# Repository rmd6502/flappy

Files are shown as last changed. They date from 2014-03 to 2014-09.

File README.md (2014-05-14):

flappy
======

This is the source folder for the Flappy Bird in a Box project.

Contents
--------

**circuit** Eagle files

**flappy_final_v8** Not really the final version, but the final version before github

**Arduino** Modifications for the stock Arduino 1.0.5 to enable compiling for the Flappy board.

Installation Instructions
-------------------------

* Install the [Arduino](http://arduino.cc) 1.0.5 IDE.
* Copy the libraries and hardware directories into the sketchbook directory for your platform
  * C:\Documents and Settings\My Documents\Arduino
  * ${HOME}/sketchbook
  * ${HOME}/Documents/Arduino
* Install the latest avr-gcc toolchain
  * AVR Studio from [Atmel](http://www.atmel.com) if you're on Windows,
  * sudo apt-get install avr-gcc
  * [Crosspack AVR for Mac](http://www.obdev.at/products/crosspack/index.html)
* Go to the Arduino install directory
  * C:\Program Files(x86)\Arduino
  * Not sure for linux - /usr/local/Arduino?
  * /Applications/Arduino.app
* Find the hardware/tools subdirectory
* mv the avr directory to e.g. avr.save - this is an old version of the toolchain that seems to 
have problems
* Copy or link the root of your newest toolchain as 'avr' in the hardware/tools directory.
* Restart the Arduino IDE
* You should be able to choose Flappy Board as your board type, and Dragon ISP as the programmer
* Choose "upload using programmer" instead of Upload

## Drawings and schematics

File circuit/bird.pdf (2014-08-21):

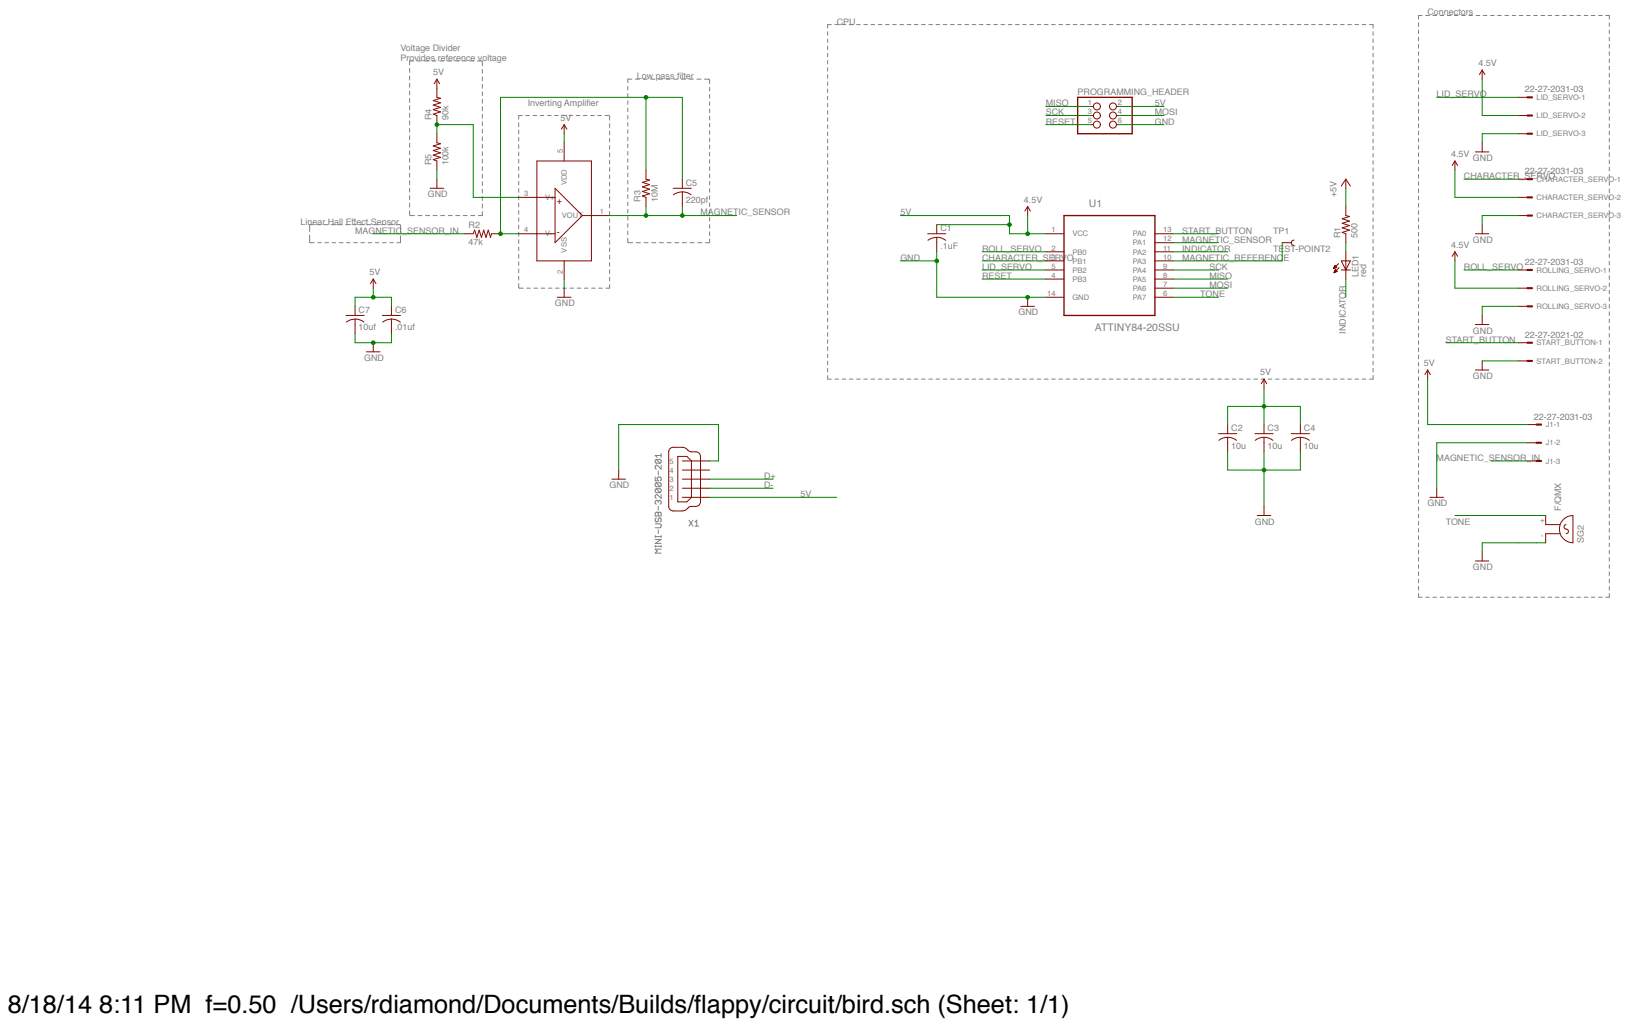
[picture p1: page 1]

Linear Hall Effect Sensor

8/18/14 8:11 PM f=0.50 /Users/rdiamond/Documents/Builds/flappy/circuit/bird.sch (Sheet: 1/1)

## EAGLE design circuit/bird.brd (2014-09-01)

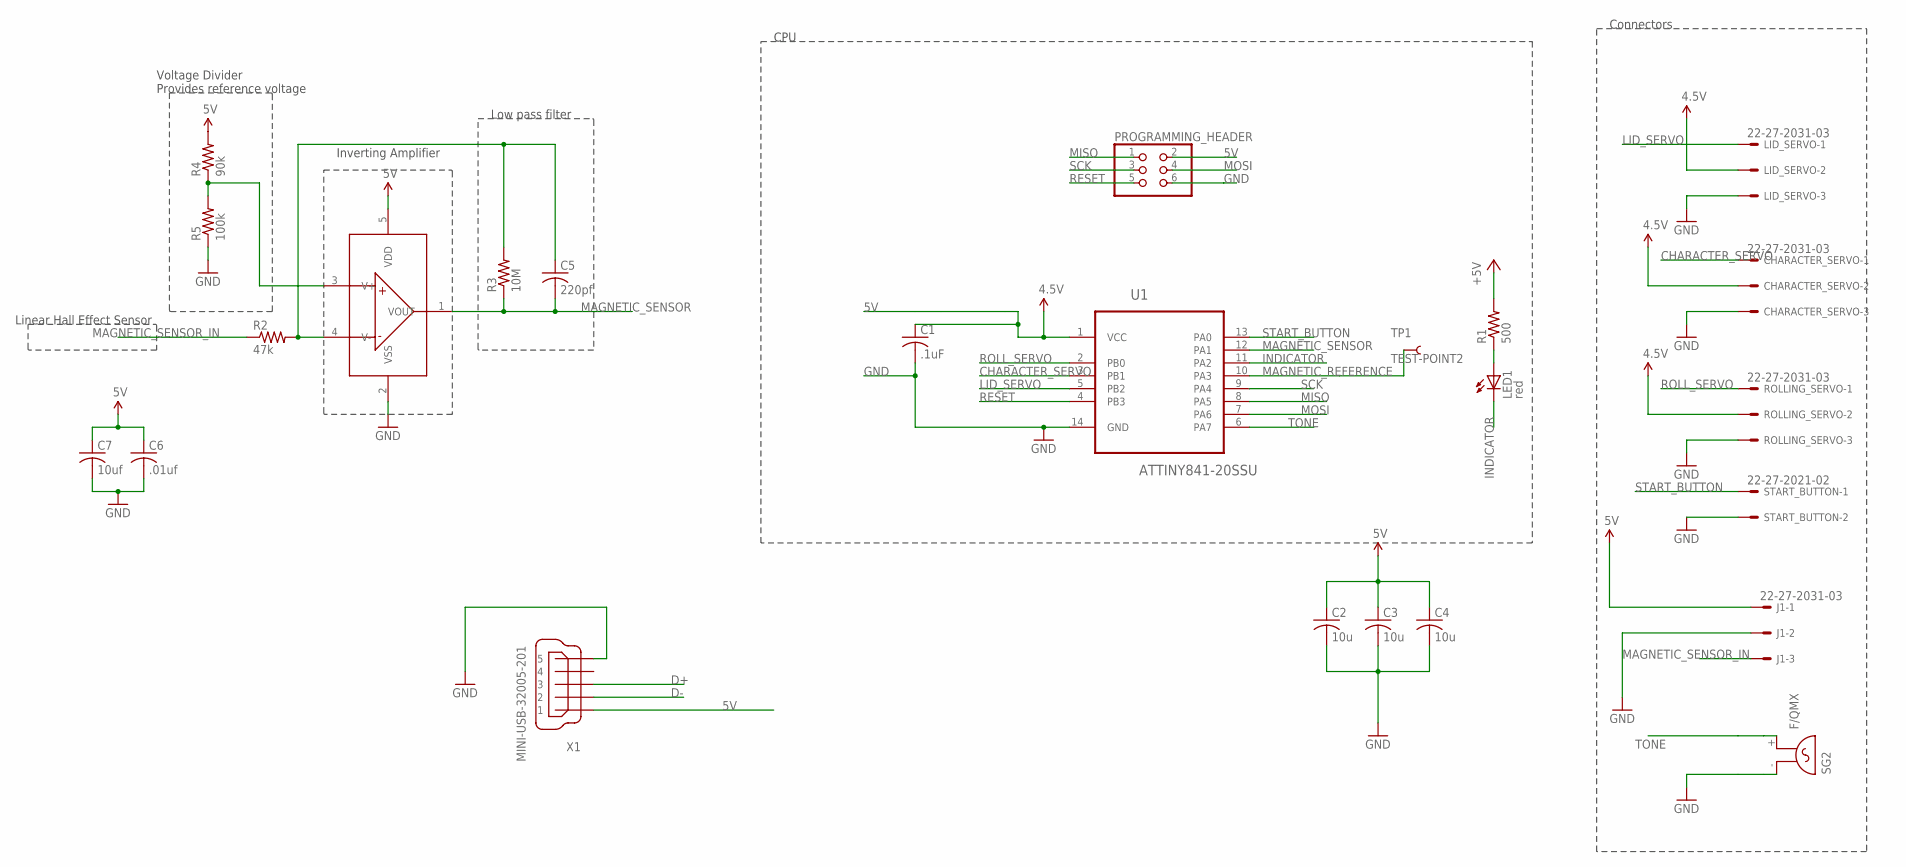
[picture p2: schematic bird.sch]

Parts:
C1: .1uF; C0603
C2, C3, C4: 10u; C0805
C5: 220pf; C0603
C6: .01uf; C0603
C7: 10uf; C0805
CHARACTER_SERVO: 22-27-2031-03; 6410-03
J1: 22-27-2031-03; 6410-03
LED1: red; SML1206
LID_SERVO: 22-27-2031-03; 6410-03
PROGRAMMING_HEADER: PINHD-2X3; 2X03
R1: 500; R0603
R2: 47k; R0603
R3: 10M; R0603
R4: 90k; R0603
R5: 100k; R0603
ROLLING_SERVO: 22-27-2031-03; 6410-03
SG2: F/QMX
START_BUTTON: 22-27-2021-02; 6410-02
TP1: TEST-POINT2; PAD.02X.02
U1: ATTINY841-20SSU; SOIC127P600X175-14N
U$5: MCP601; SOT23-5
X1: MINI-USB-32005-201; 32005-201

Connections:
5V: C1.1, C2.1, C3.1, C4.1, C6.1, C7.1, CHARACTER_SERVO.2, J1.1, LID_SERVO.2, PROGRAMMING_HEADER.2, R1.2, R4.2, ROLLING_SERVO.2, U1.1 (VCC), U$5.5 (VDD), X1.1
CHARACTER_SERVO: CHARACTER_SERVO.1, U1.3 (PB1)
D+: X1.3
D-: X1.2
GND: C1.2, C2.2, C3.2, C4.2, C6.2, C7.2, CHARACTER_SERVO.3, J1.2, LID_SERVO.3, PROGRAMMING_HEADER.6, R5.1, ROLLING_SERVO.3, SG2.- (1), START_BUTTON.2, U1.14 (GND), U$5.2 (VSS), X1.5
INDICATOR: LED1.C, U1.11 (PA2)
LID_SERVO: LID_SERVO.1, U1.5 (PB2)
MAGNETIC_REFERENCE: TP1.P$1, U1.10 (PA3)
MAGNETIC_SENSOR: C5.2, R3.1, U1.12 (PA1), U$5.1 (VOUT)
MAGNETIC_SENSOR_IN: J1.3, R2.1
MISO: PROGRAMMING_HEADER.1, U1.8 (PA5)
MOSI: PROGRAMMING_HEADER.4, U1.7 (PA6)
unnamed: LED1.A, R1.1
unnamed: C5.1, R2.2, R3.2, U$5.4 (V-)
unnamed: R4.1, R5.2, U$5.3 (V+)
RESET: PROGRAMMING_HEADER.5, U1.4 (PB3)
ROLL_SERVO: ROLLING_SERVO.1, U1.2 (PB0)
SCK: PROGRAMMING_HEADER.3, U1.9 (PA4)
START_BUTTON: START_BUTTON.1, U1.13 (PA0)
TONE: SG2.+ (2), U1.6 (PA7)

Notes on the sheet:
Linear Hall Effect Sensor
Voltage Divider Provides reference voltage
Low pass filter
Inverting Amplifier
CPU
Connectors

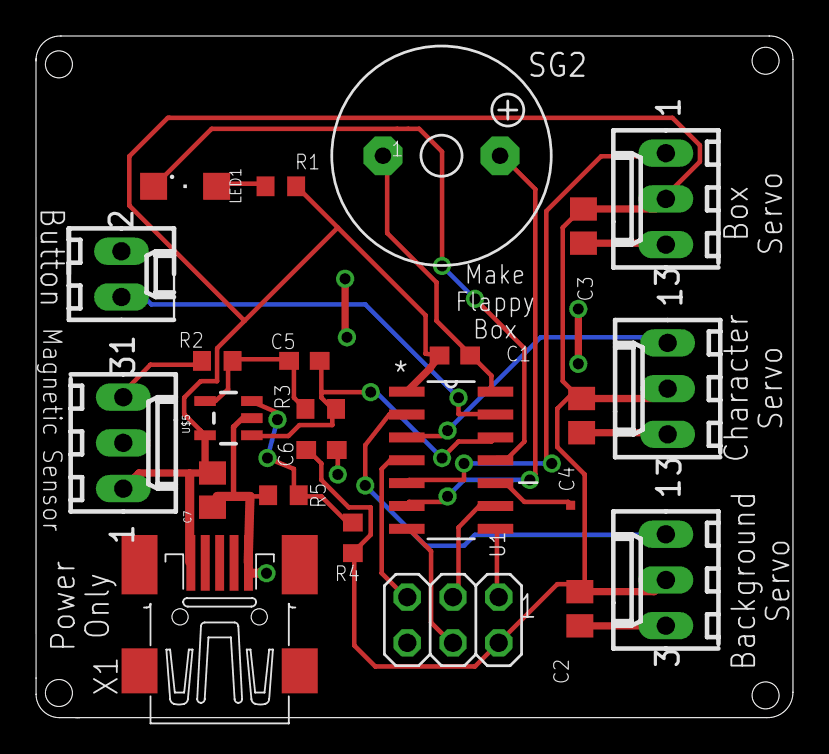
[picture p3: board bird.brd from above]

Board: 2 copper layers, 42.1 x 37.9 mm, 24 parts (0 on the bottom side), 18 nets.

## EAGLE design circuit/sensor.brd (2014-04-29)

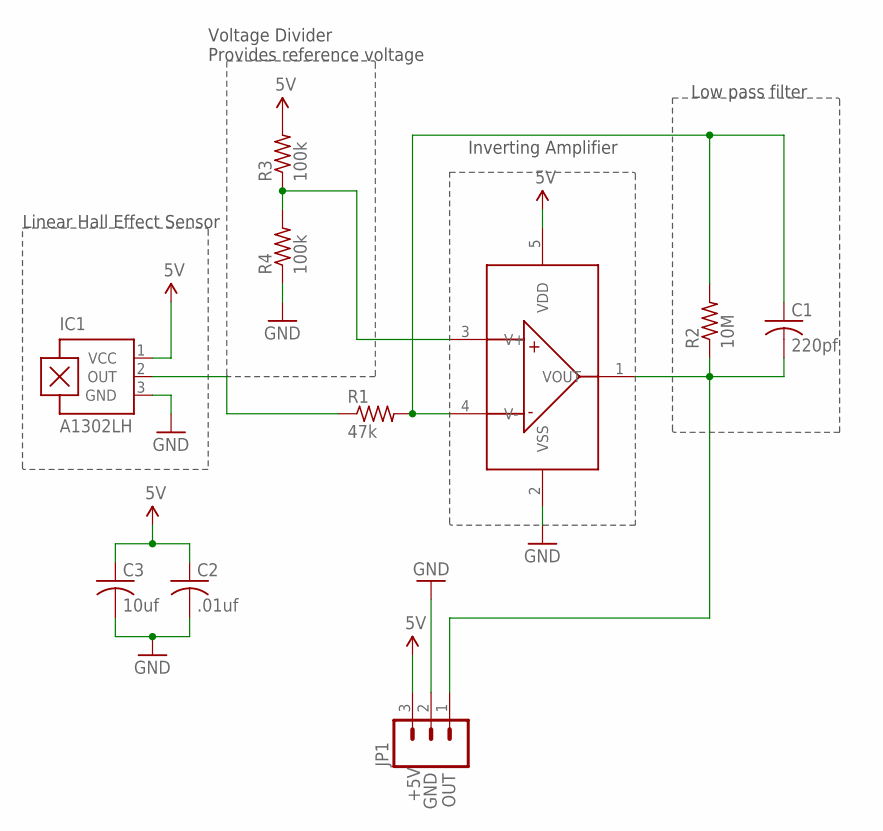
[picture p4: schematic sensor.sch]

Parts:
C1: 220pf; C0805
C2: .01uf; C0805
C3: 10uf; C0805
IC1: A1302LH; SOT23-W
JP1: M03PTH; 1X03
R1: 47k; R0805
R2: 10M; R0805
R3, R4: 100k; R0805
U$1: MCP601; SOT23-5

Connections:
5V: C2.1, C3.1, IC1.1 (VCC), JP1.3, R3.2, U$1.5 (VDD)
GND: C2.2, C3.2, IC1.3 (GND), JP1.2, R4.1, U$1.2 (VSS)
unnamed: C1.2, JP1.1, R2.1, U$1.1 (VOUT)
unnamed: IC1.2 (OUT), R1.1
unnamed: C1.1, R1.2, R2.2, U$1.4 (V-)
unnamed: R3.1, R4.2, U$1.3 (V+)

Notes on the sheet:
+5V
GND
OUT
Linear Hall Effect Sensor
Voltage Divider Provides reference voltage
Low pass filter
Inverting Amplifier

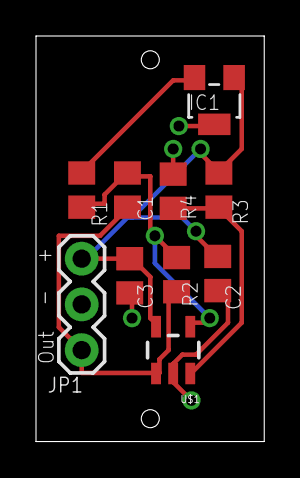
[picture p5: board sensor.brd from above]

Board: 2 copper layers, 12.7 x 22.5 mm, 10 parts (0 on the bottom side), 6 nets.

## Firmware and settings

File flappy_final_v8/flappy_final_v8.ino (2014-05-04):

#include <Servo.h> 
#include "pitches.h"

#define BOX_OPEN 90
#define BOX_CLOSE 0

#define CHARACTER_BOTTOM 40
#define CHARACTER_TOP 85

const uint8_t magnetPin = 1;     // the number of the reed switch
const uint8_t buttonPin = 0;  // the number of the pushbutton pin for bird
const uint8_t speakerPin = 7;
const uint8_t rollServoPin = 10;
const uint8_t characterServoPin = 9;
const uint8_t lidServoPin = 8;
const uint8_t ledPin =  2;      // the number of the LED pin

uint16_t magnetState = 0;         // variable
uint8_t buttonState = 0;         // variable 
uint8_t birdup = CHARACTER_BOTTOM; //start 
boolean released = true;  
boolean in_game =false;
Servo myservoRoll;
Servo myservoBird;
Servo myservoGame;

int melody[] = {
  NOTE_C4, NOTE_G3,NOTE_G3, NOTE_A3, NOTE_G3,0, NOTE_B3, NOTE_C4};// notes in the melody:
uint8_t noteDurations[] = {
  4, 8, 8, 4,4,4,4,4 }; // note durations: 4 = quarter note, 8 = eighth note, etc.:

int jumpmusic[] = {
  NOTE_A3};// notes in the melody:
uint8_t jumpDurations[] = {
  4}; // note durations: 4 = quarter note, 8 = eighth note, etc.:

void setup() 
{ 
  myservoBird.attach(characterServoPin);
  myservoRoll.attach(rollServoPin);
  myservoGame.attach(lidServoPin);
  myservoGame.write(BOX_CLOSE); 
  pinMode(magnetPin, INPUT);  //reed
  pinMode(buttonPin, INPUT_PULLUP); //button 
  pinMode(ledPin, OUTPUT);
} 

void loop() {
  magnetState = analogRead(magnetPin);
  buttonState = digitalRead(buttonPin);

  //start game 
  if (buttonState == LOW && in_game==false){
    myservoGame.write(BOX_OPEN); //open box
    birdup=CHARACTER_BOTTOM; //bird position
    delay (700);
    myservoRoll.write(60); //roll background

    in_game=true;
    released = false;
  }
  if(in_game==true)
  {
    if ((buttonState == LOW) && released ==true)
    {
      released = false;    
      if(birdup > 10){
        birdup-=10; //going up

      }
      for (int thisNote = 0; thisNote < (sizeof(jumpmusic)/sizeof(jumpmusic[0])); thisNote++) {
        int jumpDuration = 1000/jumpDurations[thisNote];
        tone(speakerPin, jumpmusic[thisNote],jumpDuration);
        int pauseBetweenNotes = jumpDuration * 13 / 10;
        delay(pauseBetweenNotes);
      }
    }
    else
    {
      if(birdup < CHARACTER_TOP){
        birdup+=1; //going down
        delay(10);
      }
    }
    if(buttonState == HIGH)
    {
      released = true;
    }

    myservoBird.write(birdup);
    delay (50);

    //game over; when bird hits ground
    if (birdup >= CHARACTER_TOP)
    {
      game_over();
    }
    //game over: when bird hit pipes
    if (magnetState == LOW) 
    {    
      game_over();
    }
  }

}

void game_over(){
  //reset all the variables
  in_game =false;
  birdup = CHARACTER_BOTTOM;
  released = true;
  myservoRoll.write(90); //stop roll background
  myservoGame.write(BOX_CLOSE); //close game box
  myservoBird.write(birdup);//bird go back to position 40
  digitalWrite(ledPin, HIGH);
  for (int thisNote = 0; thisNote < (sizeof(melody)/sizeof(melody[0])); thisNote++) {
    int noteDuration = 1000/noteDurations[thisNote];
    tone(speakerPin, melody[thisNote],noteDuration);
    int pauseBetweenNotes = noteDuration * 13 / 10;
    delay(pauseBetweenNotes);
  }
}

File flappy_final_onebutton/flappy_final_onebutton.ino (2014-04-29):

#include <Servo.h> 
#include "pitches.h"
const int magnetPin = 1;     // the number of the reed switch
const int tapPin = 0;        // the number of the pushbutton pin for bird
const int carPin = 2;        // the number of the pushbutton pin for the car
const int ledPin =  3;      // the number of the LED pin
int magnetState = 0;         // variable
int tapState = 0;         // variable 
int carState = 0;         // variable 
int location = 40; //start 
boolean released = true;  
boolean in_tap_game =false;
boolean in_car_game =false;
Servo myservoRoll;
Servo myservoBird;
Servo myservoGame;
int melody[] = {
  NOTE_C4, NOTE_G3,NOTE_G3, NOTE_A3, NOTE_G3,0, NOTE_B3, NOTE_C4};// notes in the melody:
int noteDurations[] = {
  4, 8, 8, 4,4,4,4,4 }; // note durations: 4 = quarter note, 8 = eighth note, etc.:

int jumpmusic[] = {
  NOTE_A3};// notes in the melody:
int jumpDurations[] = {
  4}; // note durations: 4 = quarter note, 8 = eighth note, etc.:

void setup() 
{ 
  myservoBird.attach(6);
  myservoRoll.attach(5);
  myservoGame.attach(8);
  myservoGame.write(0); 
  pinMode(magnetPin, INPUT);  //reed
  pinMode(tapPin, INPUT);
  pinMode(carPin, INPUT);
  pinMode(ledPin, OUTPUT);   
  digitalWrite(magnetPin, HIGH);   //internal pullup
} 

void loop() {
  magnetState = digitalRead(magnetPin);
  tapState = digitalRead(tapPin);
  carState = digitalRead(carPin);

  //start game 
  if (tapState == HIGH && in_tap_game==false && in_car_game==false){
    myservoGame.write(85); //open box
    location=40; //bird position
    delay (700);
    myservoRoll.write(60); //roll background

    in_tap_game=true;
  }
  if(in_tap_game==true)
  {
    if ((tapState == HIGH) && released ==true)
    {
      released = false;    
      if(location > 10){
        location-=10; //going up

      }
      for (int thisNote = 0; thisNote < 1; thisNote++) {
        int jumpDuration = 1000/jumpDurations[thisNote];
        tone(8, jumpmusic[thisNote],jumpDuration);
        int pauseBetweenNotes = jumpDuration * 1.30;
        delay(pauseBetweenNotes);
        noTone(1);
      }
    }
    else
    {
      if(location < 85){
        location+=1; //going up
        delay(10);
      }
    }
    if(tapState == LOW)
    {
      released = true;
    }

    myservoBird.write(location);
    delay (50);

    //game over; when bird hits ground
    if (location >84)
    {
      game_over();
    }
    //game over: when bird hit pipes
    if (magnetState == LOW) 
    {    
      game_over();
    }
  }
  
  
  
  //start   CAR game 
  if (carState == HIGH && in_tap_game==false && in_car_game==false){
    myservoGame.write(85); //open box
    location=40; //bird position
    delay (700);
    myservoRoll.write(60); //roll background

    in_car_game=true;
  }
  if(in_car_game==true)
  {
    if (tapState == HIGH)
    {
      location+=3;
    }
    if (carState == HIGH)
    {
      location-=3;
    }
    myservoBird.write(location);
    delay (50);

    //game over; when bird hits ground
    if (location >84 || location<0)
    {
      game_over();
    }
    //game over: when bird hit pipes
    if (magnetState == LOW) 
    {    
      game_over();
    }
  }

}

void game_over(){
  //reset all the variables
  in_car_game =false;
  in_tap_game =false;
  location = 40;
  released = true;
  myservoRoll.write(90); //stop roll background
  myservoGame.write(0); //close game box
  myservoBird.write(location);//bird go back to position 40
  digitalWrite(ledPin, HIGH);
  for (int thisNote = 0; thisNote < 8; thisNote++) {
    int noteDuration = 1000/noteDurations[thisNote];
    tone(8, melody[thisNote],noteDuration);
    int pauseBetweenNotes = noteDuration * 1.30;
    delay(pauseBetweenNotes);
    noTone(8);
  }
}

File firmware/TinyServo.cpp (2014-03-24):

#include <Arduino.h>
#include <avr/io.h>
#include <avr/interrupt.h>
#include <SoftwareSerial.h>

#include "TinyServo.h"

extern SoftwareSerial mySerial;

static volatile uint16_t servopwm[NUM_SERVOS];
static volatile uint8_t servoindex;
static volatile uint8_t attached[NUM_SERVOS];

TinyServo tinyServo;

TinyServo::TinyServo()
{
  for (uint8_t pin=0; pin < NUM_SERVOS; ++pin) {
    attached[pin] = 0;
  }
  // TIMER1 SETUP FOR SERVOS
	// -----------------------
	// set Timer1 to clk/64 and 9-bit fast PWM
	// this is a period of 2.048ms for 16MHz clk
	// when multiplexed on 8 servos, this gives a 16ms period
	// RMD: clk/8 for 8MHz = 1MHz and fast PWM with ICR1 = 2100
	cli();
	ICR1 = 2100;
	TCNT1 = 0;
	TCCR1A = (0x02 << WGM10);
	// enable Timer1 compare match and overflow interrupts
	TIMSK1 = 0x03;
	// -----------------------
	
	// set initial servo index
	servoindex = 0;
	TCNT1 = ICR1 - 64;	// so we overflow first
	
	// set all servos to neutral (375 = 1.500ms)
	for (int i=0; i < NUM_SERVOS; ++i) {
		servopwm[i] = 0;
	}
	
	// start the clock last
	TCCR1B = (0x03 << WGM12) | (2 << CS10);
	sei();
}

void TinyServo::attach(uint8_t servoNumber)
{
  digitalWrite(servoNumber, LOW);
  pinMode(servoNumber, OUTPUT);
  attached[servoNumber] = 1;
}

void TinyServo::detach(uint8_t servoNumber)
{
  attached[servoNumber] = 0;
}

void TinyServo::write(uint8_t servoNumber, float angle)
{
  uint16_t count = 900 + (1200.0f * angle / 180.0f);
  mySerial.print("count "); mySerial.println(count);
  if (count < 900) {
    count = 900;
  }
  if (count > 2100) {
    count = 2100;
  }
  servopwm[servoNumber] = count;
}

// INTERRUPT SERVICE ROUTINES
// --------------------------

ISR(TIM1_COMPA_vect)
{
	// interrupt on Timer1 compare match
	// (end of the servo pulse)
	
	// end servo pulse on the appropriate pin
	// faster version of digitalWrite(servoindex, LOW);
        if (attached[servoindex]) {
        	if(servoindex <= 7)
        	{
        		PORTA &= ~(1 << servoindex);
        	}
        	else
        	{
        		PORTB &= ~(1 << (10-servoindex));
        	}
        }
      	// move on to the next servo (limit to 2-8)
      	servoindex++;
      	if(servoindex == NUM_SERVOS)
      	{
      		servoindex = 0;
      	}
	
	// set the compare match to the new servo pulse duration
	OCR1A = servopwm[servoindex];

	return;
}

ISR(TIM1_OVF_vect)
{
	// interrupt on Timer1 overflow
	// start of the next servo pulse
	
	// start servo pulse on the appropriate pin
	// faster version of digitalWrite(servoindex, HIGH);
        if (attached[servoindex]) {
        	if(servoindex <= 7)
        	{
        		PORTA |= (1 << servoindex);
        	}
        	else
        	{
        		PORTB |= (1 << (10-servoindex));
        	}
        }
	
	return;
}

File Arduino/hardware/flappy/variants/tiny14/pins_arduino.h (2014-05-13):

/*
  pins_arduino.c - pin definitions for the Arduino board
  Part of Arduino / Wiring Lite

  Copyright (c) 2005 David A. Mellis

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
  $Id: pins_arduino.c 565 2009-03-25 10:50:00Z dmellis $

  Modified 28-08-2009 for attiny84 R.Wiersma
  Modified 09-10-2009 for attiny45 A.Saporetti
*/

#ifndef Pins_Arduino_h
#define Pins_Arduino_h

#include <avr/pgmspace.h>

// ATMEL ATTINY84 / ARDUINO
//
//                           +-\/-+
//                     VCC  1|    |14  GND
//             (D 10)  PB0  2|    |13  AREF (D  0)
//             (D  9)  PB1  3|    |12  PA1  (D  1) 
//                     PB3  4|    |11  PA2  (D  2) 
//  PWM  INT0  (D  8)  PB2  5|    |10  PA3  (D  3) 
//  PWM        (D  7)  PA7  6|    |9   PA4  (D  4) 
//  PWM        (D  6)  PA6  7|    |8   PA5  (D  5)        PWM
//                           +----+

const static uint8_t A0 = 0;
const static uint8_t A1 = 1;
const static uint8_t A2 = 2;
const static uint8_t A3 = 3;
const static uint8_t A4 = 4;
const static uint8_t A5 = 5;
const static uint8_t A6 = 6;
const static uint8_t A7 = 7;

#define digitalPinToPCICR(p)    ( ((p) >= 0 && (p) <= 10) ? (&GIMSK) : ((uint8_t *)0) )
#define digitalPinToPCICRbit(p) ( ((p) <= 7) ? PCIE0 : PCIE1 )
#define digitalPinToPCMSK(p)    ( ((p) <= 7) ? (&PCMSK0) : (((p) <= 10) ? (&PCMSK1) : ((uint8_t *)0)) )
#define digitalPinToPCMSKbit(p) ( ((p) <= 7) ? (p) : (10 - (p)) )

#ifdef ARDUINO_MAIN

// these arrays map port names (e.g. port B) to the
// appropriate addresses for various functions (e.g. reading
// and writing)
const uint16_t PROGMEM port_to_mode_PGM[] = 
{
  NOT_A_PORT,
  (uint16_t)&DDRA,
  (uint16_t)&DDRB,
};

const uint16_t PROGMEM port_to_output_PGM[] = 
{
  NOT_A_PORT,
  (uint16_t)&PORTA,
  (uint16_t)&PORTB,
};

const uint16_t PROGMEM port_to_input_PGM[] = 
{
  NOT_A_PORT,
  (uint16_t)&PINA,
  (uint16_t)&PINB,
};

const uint8_t PROGMEM digital_pin_to_port_PGM[] = 
{
  PA, /* 0 */
  PA,
  PA,
  PA,
  PA,
  PA,
  PA,
  PA,
  PB, /* 8 */
  PB,
  PB,
};

const uint8_t PROGMEM digital_pin_to_bit_mask_PGM[] = 
{
  _BV(0), /* port A */
  _BV(1),
  _BV(2),
  _BV(3),
  _BV(4),
  _BV(5), 
  _BV(6),
  _BV(7),
  _BV(2), /* port B */
  _BV(1),
  _BV(0),
};

const uint8_t PROGMEM digital_pin_to_timer_PGM[] = 
{
  NOT_ON_TIMER,
  NOT_ON_TIMER,
  NOT_ON_TIMER,
  NOT_ON_TIMER, 
  NOT_ON_TIMER,
  TIMER1B, /* OC1B */
  TIMER1A, /* OC1A */
  TIMER0B, /* OC0B */
  TIMER0A, /* OC0A */
  NOT_ON_TIMER,
  NOT_ON_TIMER,
};

#endif

#endif

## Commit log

2014-02-23 add circuit
    [bird.brd, bird.sch]
2014-02-23 update circuit to add programming header
    [bird.brd, bird.sch]
2014-02-24 a few changes
    [bird.brd]
2014-02-24 add copyright
    [bird.brd]
2014-02-24 add mounting holes, labels
    [bird.brd]
2014-03-05 add LED
    [bird.brd, bird.sch]
2014-03-27 update circuit
    [bird.brd, bird.sch]
2014-03-28 neaten board
    [bird.brd]
2014-03-28 more board tweaks
    [bird.brd]
2014-03-28 fix trace
    [bird.brd]
2014-04-01 add servo
    [bird.brd]
2014-04-21 add sensor
    [bird.brd, bird.sch, sensor.brd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]
2014-04-21 add comments
    [sensor.sch]
2014-04-21 add frame
    [sensor.sch]
2014-04-22 update sensor
    [bird.sch, sensor.brd]
2014-04-25 use constants
    [bird.brd, bird.sch]
2014-04-26 new layout
    [bird.brd, bird.sch]
2014-04-29 sensor update
2014-04-29 move labels
    [bird.brd]
2014-05-04 cleanups and fix sketch
    [bird.brd, bird.sch]
2014-05-11 update circuit, logo
    [bird.brd, bird.sch]
2014-05-12 0603 and gnd
    [bird.brd, bird.sch]
2014-05-13 bottom logo and labels
    [bird.brd]
2014-05-13 add arduino mods
    [bird.brd]
2014-05-18 update board
    [bird.brd, bird.sch]
2014-06-22 tweak board
    [bird.brd]
2014-08-15 mods for new board
2014-08-19 add schematic
2014-09-01 update tiny84hall
    [bird.brd, bird.sch]

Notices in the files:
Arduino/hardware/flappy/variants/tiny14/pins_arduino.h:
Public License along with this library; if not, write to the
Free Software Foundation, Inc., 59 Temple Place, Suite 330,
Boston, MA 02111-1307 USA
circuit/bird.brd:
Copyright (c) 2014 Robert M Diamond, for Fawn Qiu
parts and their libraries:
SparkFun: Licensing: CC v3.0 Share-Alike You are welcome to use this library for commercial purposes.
